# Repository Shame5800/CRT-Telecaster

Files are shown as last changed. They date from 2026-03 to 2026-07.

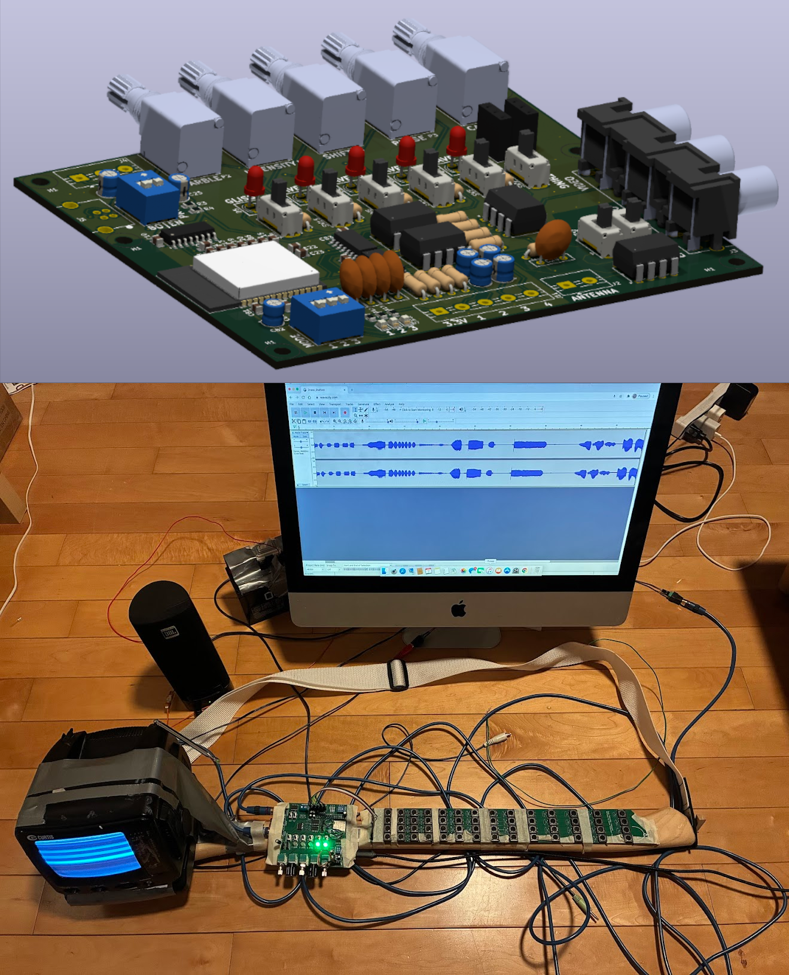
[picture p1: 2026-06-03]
hero.png

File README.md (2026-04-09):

Members

Shane Pomajambo, Electrical Engineering Student (2026)
Shanepomajambo16@vt.edu

Mentor

Arthur Ball

Current Status

IN PROGRESS

Project Overview

The purpose of this project is to create the CRT Telecaster guitars used by the Band ELECTRONICOS FANTASTICOS (https://www.youtube.com/@ELECTRONICOSFANTASTICOS_YT). The way it works is that audio signals such as square, sine, and triangle waves are sent to the video jack of a CRT television, which leads it to display the wave in the form of white and black bars. Since CRTs are a significant source of EM radiation, the EM waves can be picked up with either an inductor or by connecting the + end of an active speaker system and inducing voltage through the capacitive effect of touching the screen. Notes can be played, and the sound can be changed by moving your hand closer or farther to the screen, similar to a therevin type insturment.

The design of this instrument uses a Driver PCB equipped with an ESP32. The DAC modules built into the dev board act as a wave generator, which generates sound waves to feed into the CRT input. In order to play a certain note, 4 ADC pins with 1K resistors to ground are connected to a button and resistor array that form a 3.3V voltage divider. Values are chosen in order to be 0.15V, and each button represented a fret, similar to how a guitar would be played. Several buttons and knobs are also included to have programable affects, such as changing the type of wave, holding inputs, or having sound effects.

Through other Virginia Tech maker spaces, a working prototype has been created. However, issues still exist with grounding, playing different notes, reliability, and compactness. The main goal of the project will be to further improve the design.

Educational Value Added

One primary educational aspect of the project will be the development of the PCB. Through other personal projects using copper plate PCBS and working on debugging boards on design teams, I have become very familiar with KiCAD. This project will allow me to continue developing this skill while also introducing me to the proper PCB design principles and standards in the industry. The first educational aspect of the redesign of the telecasters' driver board is that I’m aiming to include an onboard ESP32 WROOM chip rather than a dev board, as it would give me exposure to integrating microprocessors directly on the board with programmer chips and USB ports for a more finished product. In addition, since previous designs had relied on copper plate milling and therefore had to follow different design considerations, I can focus on making the redesign compact, easy to interface with , and following proper PCB design principles.

There is also lots of educational value in programming as well. The inclusion of SPI DAC modules or other devices will expose me to embedded systems. In addition, I’ll be able to practice using hardware interrupts and optimizing code when controlling the wave generator.

The project’s development as a whole will give me lots of experience in planning, cost management/optimization, and debugging. Additionally, since very little information exists on how ELECTRONICOS FANTASTICOS’s instruments work, I'm also planning on creating tutorials and documentation on the project’s progress, giving me experience with open source documentation and technical writing.

Tasks

<!-- Your Text Here. You may work with your mentor on this later when they are assigned -->

Design Decisions

<!-- Your Text Here. You may work with your mentor on this later when they are assigned -->

Design Misc

<!-- Your Text Here. You may work with your mentor on this later when they are assigned -->

Steps for Documenting Your Design Process

<!-- Your Text Here. You may work with your mentor on this later when they are assigned -->

BOM + Component Cost

<!-- Your Text Here. You may work with your mentor on this later when they are assigned -->

Timeline

<!-- Your Text Here. You may work with your mentor on this later when they are assigned -->

Useful Links

<!-- Your Text Here. You may work with your mentor on this later when they are assigned -->

Log

<!-- Your Text Here. You may work with your mentor on this later when they are assigned -->

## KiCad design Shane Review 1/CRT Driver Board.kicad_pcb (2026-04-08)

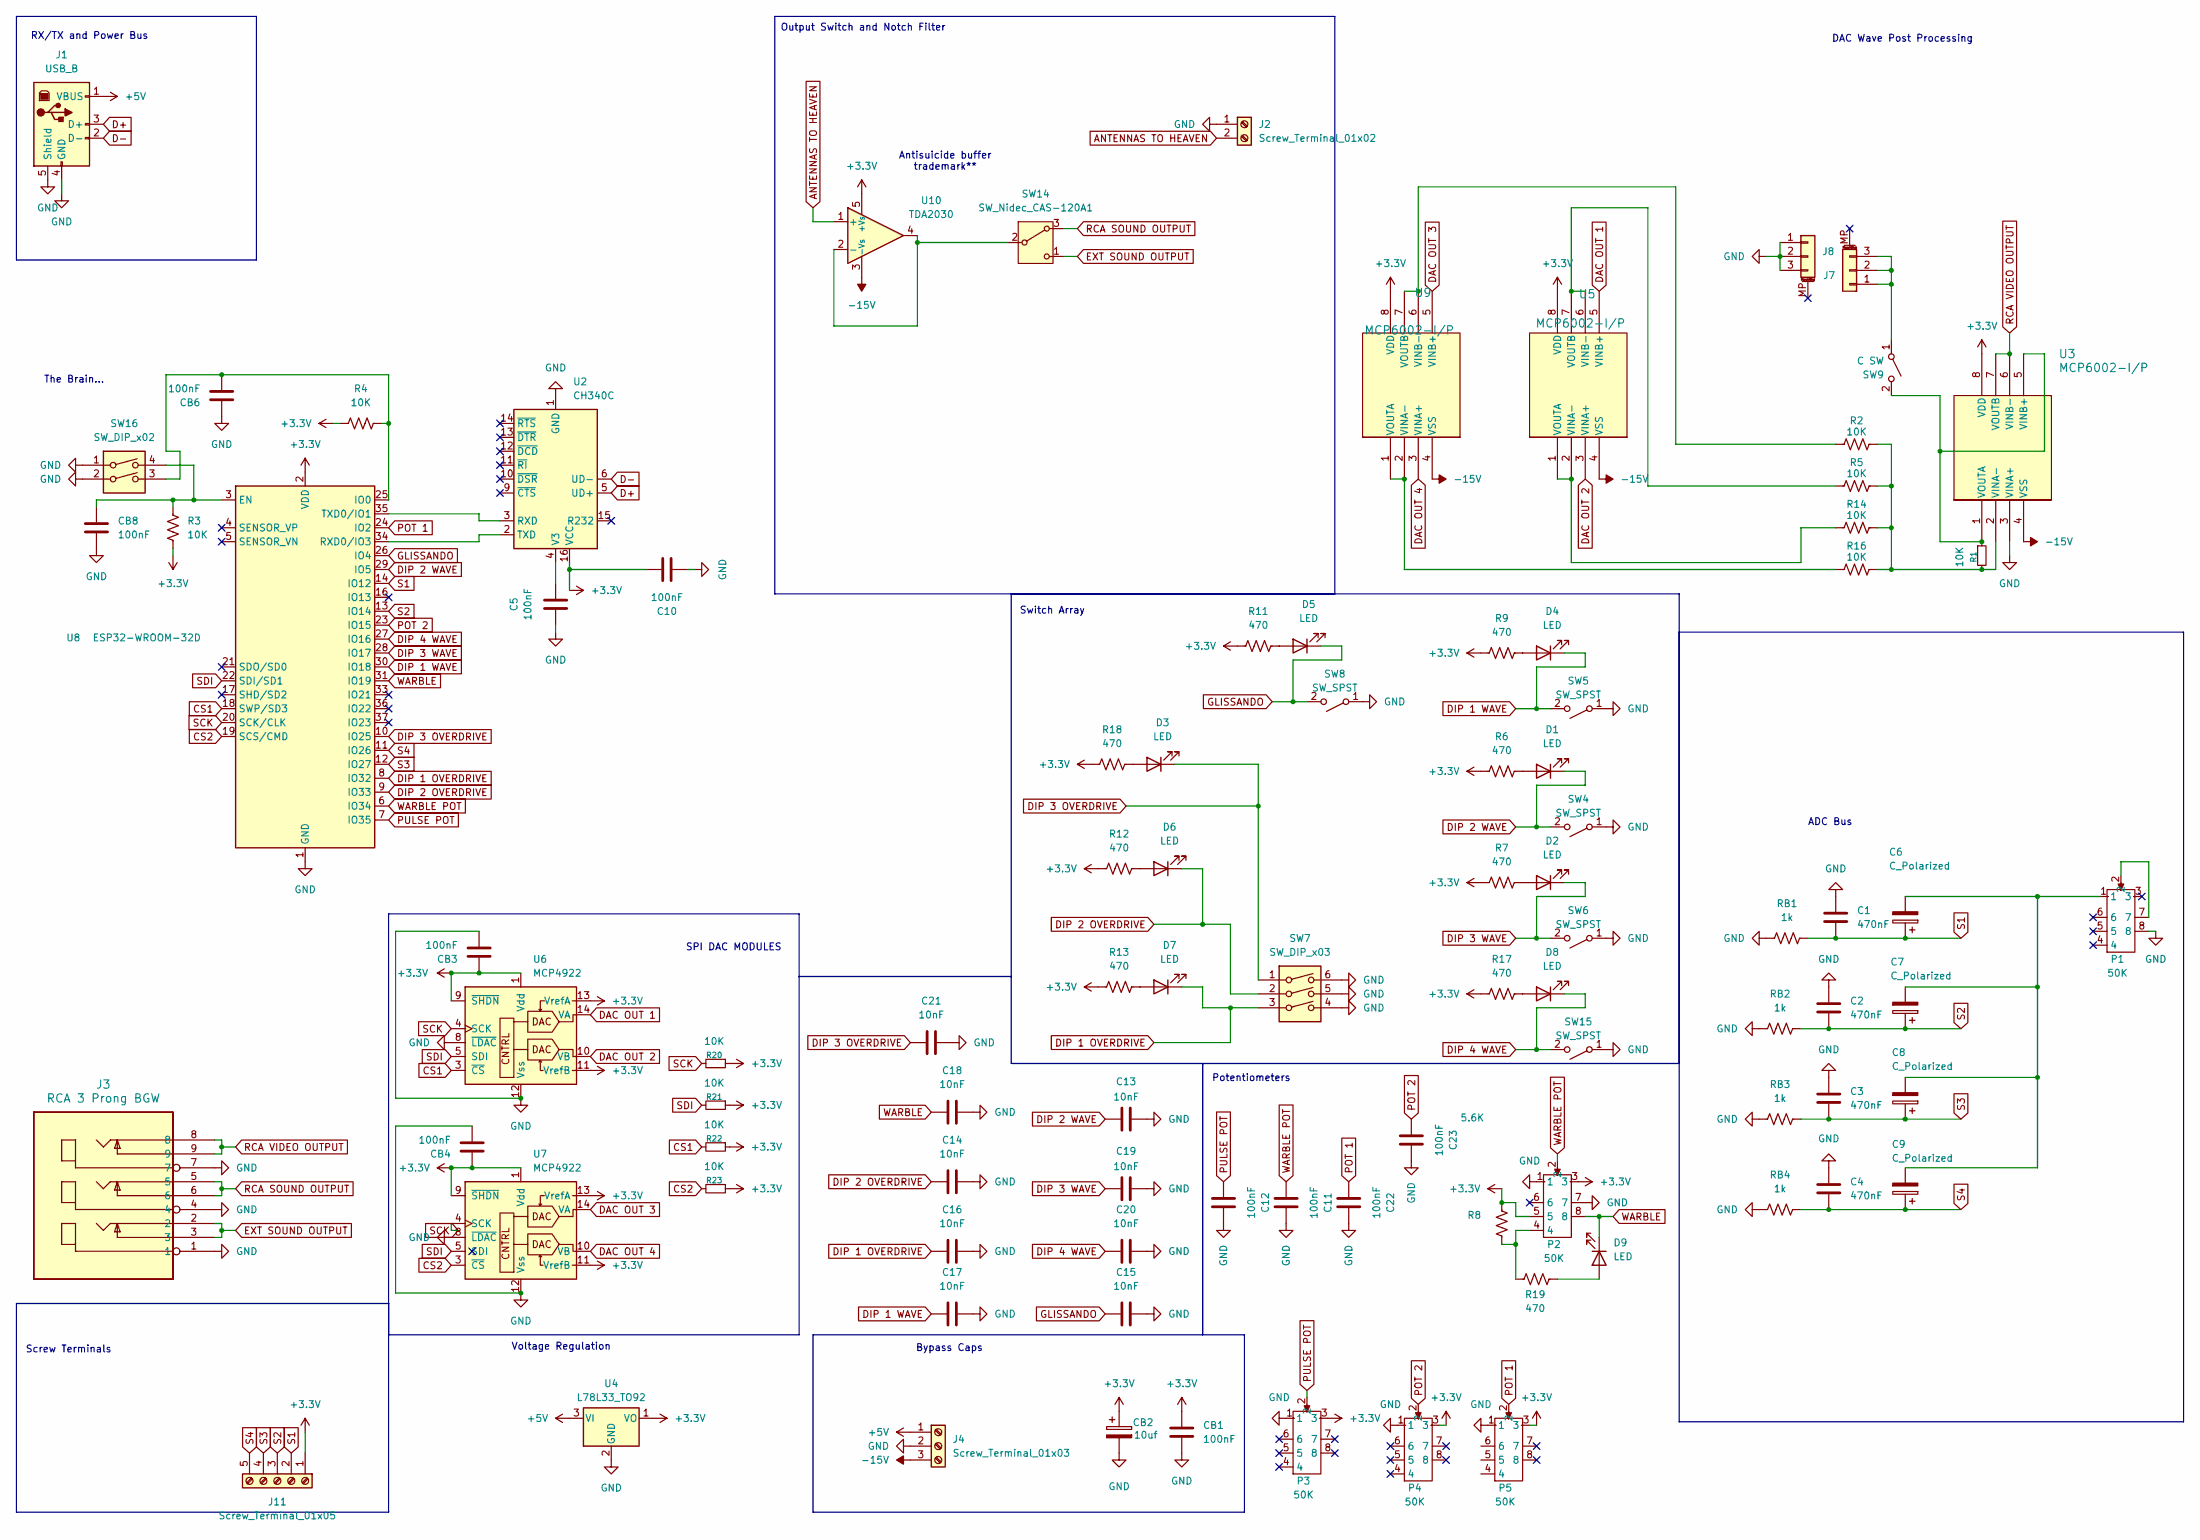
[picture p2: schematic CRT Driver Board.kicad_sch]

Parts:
C1, C2, C3, C4: 470nF; C_Disc_D8.0mm_W2.5mm_P5.00mm
C5, C10, C11, C12: 100nF; C_0805_2012Metric
C6, C7, C8, C9: C_Polarized; CP_Radial_D4.0mm_P2.00mm
C13, C14, C15, C16, C17, C18, C19, C20, C21: 10nF; C_0805_2012Metric
C22, C23: 100nF; C_0805_2012Metric_Pad1.18x1.45mm_HandSolder
CB1, CB3, CB4, CB6, CB8: 100nF; C_0805_2012Metric
CB2: 10uf; CP_Radial_D4.0mm_P2.00mm
D1, D2, D4, D5, D8, D9: LED; LED_D3.0mm
D3, D6, D7: LED; LED_0805_2012Metric
J1: USB_B; USB_B_TE_5787834_Vertical
J2: Screw_Terminal_01x02; TerminalBlock_MaiXu_MX126-5.0-02P_1x02_P5.00mm
J3: RCA 3 Prong BGW; RCA 3 Prong
J4: Screw_Terminal_01x03; TerminalBlock_MaiXu_MX126-5.0-03P_1x03_P5.00mm
J7, J8: Conn_01x03_MountingPin; PinSocket_1x03_P2.54mm_Vertical
J11: Screw_Terminal_01x05; TerminalBlock_MaiXu_MX126-5.0-05P_1x05_P5.00mm
P1, P2, P3, P4, P5: 50K; Potentiometer_Alps_RK097_Dual_Horizontal_Switch
R1, R2, R5, R14, R16: 10K; R_Axial_DIN0207_L6.3mm_D2.5mm_P7.62mm_Horizontal
R3, R4: 10K; R_0805_2012Metric
R6, R7, R9, R11, R17, R19: 470; R_Axial_DIN0207_L6.3mm_D2.5mm_P7.62mm_Horizontal
R8: 5.6K; R_Axial_DIN0207_L6.3mm_D2.5mm_P7.62mm_Horizontal
R12, R13, R18: 470; R_0805_2012Metric
R20, R21, R22, R23: 10K; R_0805_2012Metric_Pad1.20x1.40mm_HandSolder
RB1, RB2, RB3, RB4: 1k; R_Axial_DIN0207_L6.3mm_D2.5mm_P7.62mm_Horizontal
SW4, SW5, SW6, SW8, SW15: SW_SPST; SW_Slide_SPDT_Straight_CK_OS102011MS2Q
SW7: SW_DIP_x03; SW_DIP_SPSTx03_Slide_9.78x9.8mm_W7.62mm_P2.54mm
SW9: C SW; SW_Slide_SPDT_Straight_CK_OS102011MS2Q
SW14: SW_Nidec_CAS-120A1; 3 way switch
SW16: SW_DIP_x02; SW_DIP_SPSTx02_Slide_9.78x7.26mm_W7.62mm_P2.54mm
U2: CH340C; SOIC-16_3.9x9.9mm_P1.27mm
U3, U5, U9: MCP6002-I/P; PDIP8_300MC_MCH
U4: L78L33_TO92; TO-92L
U6, U7: MCP4922
U8: ESP32-WROOM-32D; esp32 WROOM without that FUCKASS attenna
U10: TDA2030; TO-220-5_P3.4x3.8mm_StaggerOdd_Lead7.13mm_TabDown

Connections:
+3.3V: C10.1, CB1.2, CB2.1, CB3.2, CB4.2, J11.1, P2.3, P2.5, P3.3, P4.3, P5.3, R3.2, R4.1, R6.1, R7.1, R8.2, R9.1, R11.1, R12.1, R13.1, R17.1, R18.1, R20.1, R21.1, R22.1, R23.1, U2.16 (VCC), U3.8 (VDD), U4.1 (VO), U5.8 (VDD), U6.1 (Vdd), U6.9 (~SHDN), U6.11 (VrefB), U6.13 (VrefA), U7.1 (Vdd), U7.9 (~SHDN), U7.11 (VrefB), U7.13 (VrefA), U8.2 (VDD), U9.8 (VDD), U10.5 (+Vs)
+5V: J1.1 (VBUS), J4.1, U4.3 (VI)
-15V: J4.3, U3.4 (VSS), U5.4 (VSS), U9.4 (VSS), U10.3 (-Vs)
ANTENNAS TO HEAVEN: J2.2, U10.1 (+)
CS1: R22.2, U6.3 (~CS), U8.18 (SWP/SD3)
CS2: R23.2, U7.3 (~CS), U8.19 (SCS/CMD)
D+: J1.3 (D+), U2.5 (UD+)
D-: J1.2 (D-), U2.6 (UD-)
DAC OUT 1: U5.5 (VINB+), U6.14 (VA)
DAC OUT 2: U5.3 (VINA+), U6.10 (VB)
DAC OUT 3: U7.14 (VA), U9.5 (VINB+)
DAC OUT 4: U7.10 (VB), U9.3 (VINA+)
DIP 1 OVERDRIVE: C16.2, D7.1 (K), SW7.3, U8.8 (IO32)
DIP 1 WAVE: C17.2, D4.1 (K), SW5.2 (B), U8.30 (IO18)
DIP 2 OVERDRIVE: C14.2, D6.1 (K), SW7.2, U8.9 (IO33)
DIP 2 WAVE: C13.2, D1.1 (K), SW4.2 (B), U8.29 (IO5)
DIP 3 OVERDRIVE: C21.2, D3.1 (K), SW7.1, U8.10 (IO25)
DIP 3 WAVE: C19.2, D2.1 (K), SW6.2 (B), U8.28 (IO17)
DIP 4 WAVE: C20.2, D8.1 (K), SW15.2 (B), U8.27 (IO16)
EXT SOUND OUTPUT: J3.2, J3.3, SW14.1 (C)
GLISSANDO: C15.2, D5.1 (K), SW8.2 (B), U8.26 (IO4)
GND: C1.1, C2.1, C3.1, C4.1, C5.2, C10.2, C11.1, C12.1, C13.1, C14.1, C15.1, C16.1, C17.1, C18.1, C19.1, C20.1, C21.1, C22.1, C23.1, CB1.1, CB2.2, CB3.1, CB4.1, CB6.2, CB8.1, J1.4 (GND), J1.5 (Shield), J2.1, J3.1, J3.4, J3.7, J4.2, J8.1, J8.2, J8.3, P1.8, P2.1, P2.7, P3.1, P4.1, P5.1, RB1.1, RB2.1, RB3.1, RB4.1, SW4.1 (A), SW5.1 (A), SW6.1 (A), SW7.4, SW7.5, SW7.6, SW8.1 (A), SW15.1 (A), SW16.1, SW16.2, U2.1 (GND), U3.3 (VINA+), U4.2 (GND), U6.8 (~LDAC), U6.12 (Vss), U7.8 (~LDAC), U7.12 (Vss), U8.1 (GND), U8.15 (GND), U8.38 (GND), U8.39 (GND)
unnamed: C6.2, C7.2, C8.2, C9.2, P1.1
unnamed: D1.2 (A), R6.2
unnamed: D2.2 (A), R7.2
unnamed: D3.2 (A), R18.2
unnamed: D4.2 (A), R9.2
unnamed: D5.2 (A), R11.2
unnamed: D6.2 (A), R12.2
unnamed: D7.2 (A), R13.2
unnamed: D8.2 (A), R17.2
unnamed: D9.2 (A), R19.2
unnamed: J7.1, J7.2, J7.3, SW9.1 (A)
unnamed: P1.2, P1.7
unnamed: P2.4, R8.1, R19.1
unnamed: R1.1, SW9.2 (B), U3.1 (VOUTA), U3.5 (VINB+)
unnamed: SW14.2 (B), U10.2 (-), U10.4
unnamed: U2.3 (RXD), U8.35 (TXD0/IO1)
unnamed: U2.2 (TXD), U8.34 (RXD0/IO3)
unnamed: C5.1, U2.4 (V3)
unnamed: R1.2, R2.2, R5.2, R14.2, R16.2, U3.2 (VINA-)
unnamed: R14.1, U5.1 (VOUTA), U5.2 (VINA-)
unnamed: R5.1, U5.6 (VINB-), U5.7 (VOUTB)
unnamed: CB8.2, R3.1, SW16.4, U8.3 (EN)
unnamed: CB6.1, R4.2, SW16.3, U8.25 (IO0)
unnamed: R16.1, U9.1 (VOUTA), U9.2 (VINA-)
unnamed: R2.1, U9.6 (VINB-), U9.7 (VOUTB)
POT 1: C22.2, P5.2, U8.24 (IO2)
POT 2: C23.2, P4.2, U8.23 (IO15)
PULSE POT: C12.2, P3.2, U8.7 (IO35)
RCA SOUND OUTPUT: J3.5, J3.6, SW14.3 (A)
RCA VIDEO OUTPUT: J3.8, J3.9, U3.6 (VINB-), U3.7 (VOUTB)
S1: C1.2, C6.1, J11.2, RB1.2, U8.14 (IO12)
S2: C2.2, C7.1, J11.3, RB2.2, U8.13 (IO14)
S3: C3.2, C8.1, J11.4, RB3.2, U8.12 (IO27)
S4: C4.2, C9.1, J11.5, RB4.2, U8.11 (IO26)
SCK: R20.2, U6.4 (SCK), U7.4 (SCK), U8.20 (SCK/CLK)
SDI: R21.2, U6.5 (SDI), U7.5 (SDI), U8.22 (SDI/SD1)
WARBLE: C18.2, D9.1 (K), P2.8, U8.31 (IO19)
WARBLE POT: C11.2, P2.2, U8.6 (IO34)

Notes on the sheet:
ADC Bus
Potentiometers
Output Switch and Notch Filter
Switch Array
Antisuicide buffer trademark**
SPI DAC MODULES
DAC Wave Post Processing
Screw Terminals
Voltage Regulation
Bypass Caps
The Brain...
RX/TX and Power Bus

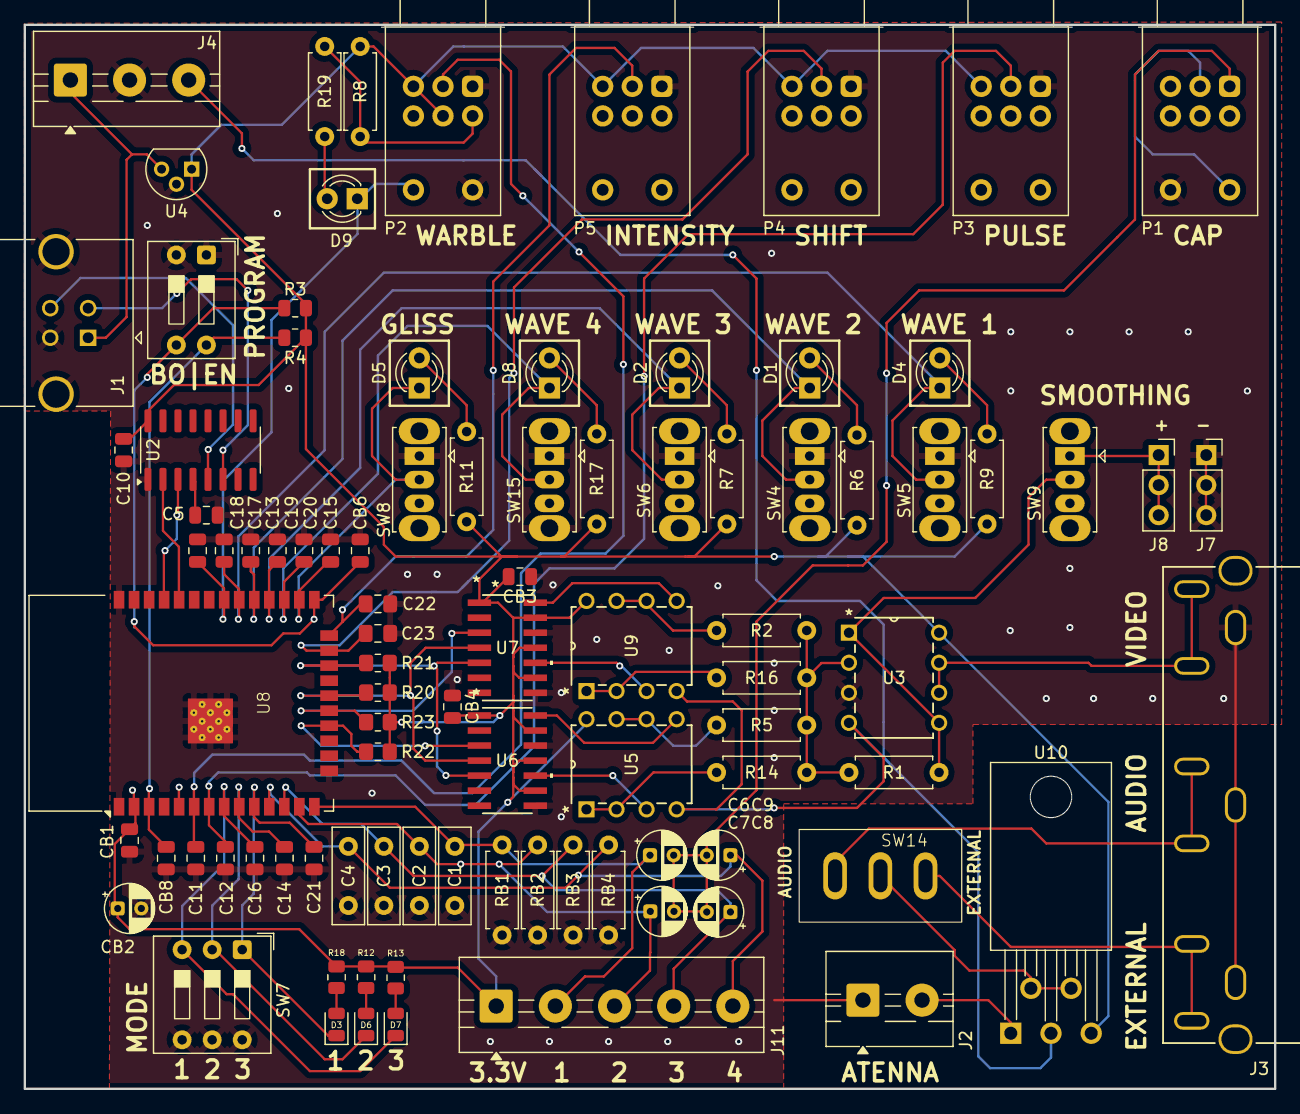
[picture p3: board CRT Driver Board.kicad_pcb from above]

Board: 2 copper layers, 105.7 x 89.9 mm, 93 parts (0 on the bottom side), 60 nets.

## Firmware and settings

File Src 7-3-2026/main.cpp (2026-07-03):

#include <Arduino.h>
#include "def.h"
#include "esp_wifi.h"
#include "esp_bt.h"
#include "global.h"
#include "wavegen.h"
#include "notes.h"
//================================================================================
//     ______           __                   _
//    /_  __/______  __/ /____  ______ ___  (_)___  __  __
//     / / / ___/ / / / //_/ / / / __ `__ \/ /_  / / / / /
//    / / (__  ) /_/ / ,< / /_/ / / / / / / / / /_/ /_/ /
//   /_/ /____/\__,_/_/|_|\__,_/_/ /_/ /_/_/ /___/\__,_/
//
//                          ______     __                     __
//                         /_  __/__  / /__  _________ ______/ /____  _____
//                          / / / _ \/ / _ \/ ___/ __ `/ ___/ __/ _ \/ ___/
//                         / / /  __/ /  __/ /__/ /_/ /__  / /_/  __/ /
//                        /_/  \___/_/\___/\___/\__,_/____/\__/\___/_/
//
//================================================================================
// 
//Tsukumizu Progamable 4 string hybrid bass guitar
//
//    Designed by Shane Sebastian Pomajambo
//
//    Originial idea by ELECTRONICOS FANTASTICOS
//
//    Special Thanks to Elias Charron, Shane Wyman, Professor Arthur Ball, and the AMP Lab at Virginia Tech
//
// Ver 2.1
// - We're in VSCode Now!
// - Created V2 PCB
// - This code is designed for the V2 PCB, and is much diffrent
// - 4 channel DACs based on SPI
// - More potential wave options plus mode selector
// - combined interupts logic with dual core architecture of ESP32
//
//
//
//
//
// Tuning =========================================================================

//Standard
int manualModifiers[] = {0,0,0,0};

//Tune down 2 frets, Used in Yoshi's Island by Glass Beach
//int manualModifiers[] = {-2,-2,-2,-2};



// Synchronous Methods ============================================================
//
//Set true for chorus, set false for octaver
bool chorus = false;
//
//
//Note Array
int notes[] = {
  Bb0,B0note,C1,Db1,D1,Eb1, E1, F1, Gb1, G1, Ab1, A1, Bb1, B1note,
  C2, Db2, D2, Eb2, E2, F2, Gb2, G2, Ab2, A2, Bb2, B2,
  C3, Db3, D3, Eb3, E3, F3, Gb3, G3, Ab3, A3, Bb3, B3,
  C4, Db4, D4, Eb4, E4, F4, Gb4, G4, Ab4, A4, Bb4, B4,
  C5, Db5, D5, Eb5, E5, F5, Gb5, G5, Ab5, A5, Bb5, B5,
  C6, Db6, D6, Eb6, E6, F6
};

//sendToWavegen() Variables
uint32_t tempPhaseIncrementChannelOne=0;
uint32_t tempPhaseIncrementChannelTwo=0;
uint32_t tempPhaseIncrementChannelThree=0;
uint32_t tempPhaseIncrementChannelFour=0;
int tempMultiplierChannelOne=0;
int tempMultiplierChannelTwo=0;
int tempMultiplierChannelThree=0;
int tempMultiplierChannelFour=0;
int tempWaveSelector=0;
hw_timer_t *timer = NULL;

//Potentiometer and user input
bool warble = false;
bool glissando = false;
int warblePot = 0;
int intensityPot=0;
int shiftPot=0;
int tempPulsePot = 0;
int modeSelector=0;

//Warble mode
int warbleDivisor;
int warbleCounter=0;
bool upwardsWarble=false;

//Shift Mode
int shiftRange=0;
int shiftModifier=0;

//Fretboard input processing
int lastPlayedFret[] = {-1,-1,-1,-1};
int requestedNote[] = {0,0,0,0};
int requestedFret[] = {-1,-1,-1,-1};
int numNotesPlaying = 0;
int totalMultiplier=0;
int noteBases[] = {6,6,6,6};

//Methods ---------------------------------------------------------------
void setFrequencies(float freq1,float freq2,float freq3,float freq4) { //Converts frequencies to increment
  // phaseIncrement = (freq * 2^32) / SAMPLE_RATE
  tempPhaseIncrementChannelOne = (uint32_t)((freq1 * 4294967296.0) / 20000);
  tempPhaseIncrementChannelTwo = (uint32_t)((freq2 * 4294967296.0) / 20000);
  tempPhaseIncrementChannelThree = (uint32_t)((freq3 * 4294967296.0) / 20000);
  tempPhaseIncrementChannelFour = (uint32_t)((freq4 * 4294967296.0) / 20000);
}

void setMultiplier(int input1,int input2,int input3,int input4){ //Sets Multipliers
  tempMultiplierChannelOne=input1;
  tempMultiplierChannelTwo=input2;
  tempMultiplierChannelThree=input3;
  tempMultiplierChannelFour=input4;
}

void sendToWaveGenerator(){ //Helper method used by sendNotes()
  portENTER_CRITICAL(&mux);
  phaseIncrementChannelOne = tempPhaseIncrementChannelOne;
  phaseIncrementChannelTwo = tempPhaseIncrementChannelTwo;
  phaseIncrementChannelThree = tempPhaseIncrementChannelThree;
  phaseIncrementChannelFour = tempPhaseIncrementChannelFour;
  multiplierChannelOne = tempMultiplierChannelOne;
  multiplierChannelTwo = tempMultiplierChannelTwo;
  multiplierChannelThree = tempMultiplierChannelThree;
  multiplierChannelFour = tempMultiplierChannelFour;
  waveSelector = tempWaveSelector;
  pulsePot = tempPulsePot;
  portEXIT_CRITICAL(&mux);
}

int processInput(int input) { //Process ADC to Fret
  input = input - 1020;
  int multiple = input / 200;
  if (input - multiple * 200 > 100) {
    multiple = multiple + 1;
  }
  if(multiple<0){
    return -1;
  }
  numNotesPlaying++;
  return multiple;
}  //end process

void playTuningChorale(){ 
  
  //In Honor of Mr Martin.
    

  setMultiplier(0,0,0,0);
  sendToWaveGenerator();
  delay(5000);
  setMultiplier(16,16,16,0);
  setFrequencies(A2,A3,A4,B5); sendToWaveGenerator(); delay(1000);
  setMultiplier(0,0,0,0); sendToWaveGenerator(); delay(50); setMultiplier(16,16,16,0);
  setFrequencies(G2,G3,G4,B5); sendToWaveGenerator(); delay(1000);
  setMultiplier(0,0,0,0); sendToWaveGenerator(); delay(50); setMultiplier(16,16,16,0);
  setFrequencies(G2,G3,G4,B5); sendToWaveGenerator(); delay(1000);
  setMultiplier(0,0,0,0); sendToWaveGenerator(); delay(50); setMultiplier(16,16,16,0);
  setFrequencies(F2,F3,F4,B5); sendToWaveGenerator(); delay(1000);
  setMultiplier(0,0,0,0); sendToWaveGenerator(); delay(50); setMultiplier(16,16,16,0);
  setFrequencies(F2,F3,F4,B5); sendToWaveGenerator(); delay(1000);
  setMultiplier(0,0,0,0); sendToWaveGenerator(); delay(50); setMultiplier(16,16,16,0);
  setFrequencies(F2,F3,F4,B5); sendToWaveGenerator(); delay(1000);
  setMultiplier(0,0,0,0); sendToWaveGenerator(); delay(50); setMultiplier(16,16,16,0);
  setFrequencies(E2,E3,E4,B5); sendToWaveGenerator(); delay(1000);
  setMultiplier(0,0,0,0); sendToWaveGenerator(); delay(50); setMultiplier(16,16,16,0);
  setFrequencies(F2,F3,F4,B5); sendToWaveGenerator(); delay(2000);
  setMultiplier(0,0,0,0);  sendToWaveGenerator(); delay(1000); setMultiplier(16,16,16,0);
  setFrequencies(F2,F3,F4,B5); sendToWaveGenerator(); delay(1000);
  setMultiplier(0,0,0,0); sendToWaveGenerator(); delay(50); setMultiplier(16,16,16,0);
  setFrequencies(G2,G3,G4,B5); sendToWaveGenerator(); delay(1000);
  setMultiplier(0,0,0,0); sendToWaveGenerator(); delay(50); setMultiplier(16,16,16,0);
  setFrequencies(G2,G3,G4,B5); sendToWaveGenerator(); delay(1000);
  setMultiplier(0,0,0,0); sendToWaveGenerator(); delay(50); setMultiplier(16,16,16,0);
  setFrequencies(A2,A3,A4,B5); sendToWaveGenerator(); delay(1000);
  setMultiplier(0,0,0,0); sendToWaveGenerator(); delay(50); setMultiplier(16,16,16,0);
  setFrequencies(F2,F3,F4,B5); sendToWaveGenerator(); delay(1000);
  setMultiplier(0,0,0,0); sendToWaveGenerator(); delay(50); setMultiplier(16,16,16,0);
  setFrequencies(Bb2,Bb3,Bb4,B5); sendToWaveGenerator(); delay(1000);
  setMultiplier(0,0,0,0); sendToWaveGenerator(); delay(50); setMultiplier(16,16,16,0);
  setFrequencies(Bb2,Bb3,Bb4,B5); sendToWaveGenerator(); delay(1000);
  setMultiplier(0,0,0,0); sendToWaveGenerator(); delay(50); setMultiplier(16,16,16,0);
  setFrequencies(A2,A3,A4,B5); sendToWaveGenerator(); delay(2000);
  setMultiplier(0,0,0,0); sendToWaveGenerator(); delay(50); setMultiplier(16,16,16,0);
  setFrequencies(F2,F3,F4,B5); sendToWaveGenerator(); delay(4000);
  setMultiplier(0,0,0,0); sendToWaveGenerator();
}

void sendNotes(){ //Send note selections to processing
  if(requestedNote[0]!=0){tempMultiplierChannelOne=totalMultiplier;} else{tempMultiplierChannelOne=0;}
  if(requestedNote[1]!=0){tempMultiplierChannelTwo=totalMultiplier;} else{tempMultiplierChannelTwo=0;}
  if(requestedNote[2]!=0){tempMultiplierChannelThree=totalMultiplier;} else{tempMultiplierChannelThree=0;}
  if(requestedNote[3]!=0){tempMultiplierChannelFour=totalMultiplier;} else{tempMultiplierChannelFour=0;}
  setFrequencies(requestedNote[0],requestedNote[1],requestedNote[2],requestedNote[3]);
  sendToWaveGenerator();
  lastPlayedFret[0]=requestedFret[0];
  lastPlayedFret[1]=requestedFret[1];
  lastPlayedFret[2]=requestedFret[2];
  lastPlayedFret[3]=requestedFret[3];
}

void processSwitches(){ //Process Mode and Wave DIP switches
  
  //Take UI measurements
  if(digitalRead(GLISSANDOPIN)==LOW){glissando=true;}
  else{glissando=false;}
  if(digitalRead(WARBLEPIN)==LOW){warble=true;}
  else{warble=false;}

  modeSelector=0;
  if(digitalRead(MODEDIP1PIN)==LOW){modeSelector+=1;}
  if(digitalRead(MODEDIP2PIN)==LOW){modeSelector+=2;}
  if(digitalRead(MODEDIP3PIN)==LOW){modeSelector+=4;}

  tempWaveSelector=0;
  if(digitalRead(WAVEDIP1PIN)==LOW){tempWaveSelector+=1;}
  if(digitalRead(WAVEDIP2PIN)==LOW){tempWaveSelector+=2;}
  if(digitalRead(WAVEDIP3PIN)==LOW){tempWaveSelector+=4;}
  if(digitalRead(WAVEDIP4PIN)==LOW){tempWaveSelector+=8;}
  
  //Base Mode Logic
  //4 string bass
  noteBases[0]=6;
  noteBases[1]=6;
  noteBases[2]=6;
  noteBases[3]=6;
  if(modeSelector==1){ //guitar lower
    noteBases[0]=18;
    noteBases[1]=18;
    noteBases[2]=18;
    noteBases[3]=18;
  }
  if(modeSelector==2){ //guitar middle
    noteBases[0]=23;
    noteBases[1]=23;
    noteBases[2]=23;
    noteBases[3]=22;
  }
  if(modeSelector==3){ //guitar higher
    noteBases[0]=28;
    noteBases[1]=28;
    noteBases[2]=27;
    noteBases[3]=27;
  }
  if(modeSelector==4){ //5 string bass lower, upper is 4 string bass
    noteBases[0]=1;
    noteBases[1]=1;
    noteBases[2]=1;
    noteBases[3]=1;
  }
  if(modeSelector==5){ //Overdrive Guitar
   noteBases[0]=38;
    noteBases[1]=38;
    noteBases[2]=37;
    noteBases[3]=37;

  }
  if(modeSelector==6){ //overdrive bass
    noteBases[0]=16;
    noteBases[1]=16;
    noteBases[2]=16;
    noteBases[3]=16;
  }
  if(modeSelector==7){
    //TBD 
    //preset modes for autoplay eventually
  }
}

void processOctaver(){ //Process Octaver or Chorus modes
  if(tempWaveSelector>=8){
    for(int i=0;i<4;i++){
      if(requestedNote[i]!=0){
        int currentNoteIndex = requestedFret[i] + (i*5) + manualModifiers[i] + noteBases[i];
        requestedNote[0]=0; requestedNote[1]=0; requestedNote[2]=0; requestedNote[3]=0;
        numNotesPlaying=0;
        if(chorus){
          requestedNote[0] = notes[currentNoteIndex];
          requestedNote[1] = notes[currentNoteIndex];
          requestedNote[2] = notes[currentNoteIndex];
          numNotesPlaying=3;
          
        }
        else{
          requestedNote[0] = notes[currentNoteIndex];
          numNotesPlaying++;
          if(currentNoteIndex-12>=0){
            requestedNote[1] = notes[currentNoteIndex-12];
            numNotesPlaying++;
          }
          if(currentNoteIndex+12<68){
            requestedNote[2] = notes[currentNoteIndex+12];
            numNotesPlaying++;
          }
        }
        break;
      }
    }
    tempWaveSelector=tempWaveSelector-8;
  }
}

void processShift(){ //Process Shift effect
  if(shiftPot>100){
    for(int i=0;i<4;i++){
      if(requestedNote[i]!=0){
        shiftRange = 2*(requestedNote[i]/30);
        
        shiftModifier = shiftPot/(4095/shiftRange);
        shiftModifier = shiftModifier - (shiftRange/2);

        requestedNote[i] = requestedNote[i]+shiftModifier;

      }
    }
  }
}


//Startup -------
void setup(){
  Serial.begin(9600);
  esp_wifi_stop();
  esp_bt_controller_disable();

  pinMode(CS1,OUTPUT);
  pinMode(CS2,OUTPUT);
 
  pinMode(S1,INPUT);
  pinMode(S2,INPUT);
  pinMode(S3,INPUT);
  pinMode(S4,INPUT);

  pinMode(WARBLEPOT,INPUT);
  pinMode(PULSEPOT,INPUT);
  pinMode(INTENSITYPOT,INPUT);
  pinMode(SHIFTPOT,INPUT);

  pinMode(GLISSANDOPIN,INPUT_PULLUP);
  pinMode(WARBLEPIN,INPUT_PULLUP);

  pinMode(WAVEDIP1PIN,INPUT_PULLUP);
  pinMode(WAVEDIP2PIN,INPUT_PULLUP);
  pinMode(WAVEDIP3PIN,INPUT_PULLUP);
  pinMode(WAVEDIP4PIN,INPUT_PULLUP);

  pinMode(MODEDIP1PIN,INPUT_PULLUP);
  pinMode(MODEDIP2PIN,INPUT_PULLUP);
  pinMode(MODEDIP3PIN,INPUT_PULLUP);

  spi.begin(SCK_PIN, -1, MOSI_PIN, -1);
  spi.beginTransaction(SPISettings(20000000, MSBFIRST, SPI_MODE0));

  digitalWrite(CS1, LOW);
  spi.transfer16(0x3000);   
  spi.transfer16(0xB000); 
  digitalWrite(CS1, HIGH);
  digitalWrite(CS2, LOW);
  spi.transfer16(0x3000);   
  spi.transfer16(0xB000); 
  digitalWrite(CS2, HIGH);

  modeSelector=0;
  if(digitalRead(MODEDIP1PIN)==LOW){modeSelector+=1;}
  if(digitalRead(MODEDIP2PIN)==LOW){modeSelector+=2;}
  if(digitalRead(MODEDIP3PIN)==LOW){modeSelector+=4;}
  Serial.println("Startup Msg");

  //May not workVVV   //It works

  xTaskCreatePinnedToCore(
    dacTask,        // function
    "DAC",          // name
    4096,           // stack size
    NULL,           // parameters
    2,              // priority
    &dacTaskHandle, // handle
    0               // core 0
  );
  


  timer = timerBegin(0, 80, true);
  timerAttachInterrupt(timer, &onTimer, true);
  timerAlarmWrite(timer, 50, true);
  timerAlarmEnable(timer);

  modeSelector=0;
  if(digitalRead(MODEDIP1PIN)==LOW){modeSelector+=1;}
  if(digitalRead(MODEDIP2PIN)==LOW){modeSelector+=2;}
  if(digitalRead(MODEDIP3PIN)==LOW){modeSelector+=4;}

  if(modeSelector==7){
    playTuningChorale();
  }


}//end setup


//Application Loop
void loop(){

  //Fret Debugging
  // int reading = analogRead(S1);
  // Serial.println(reading);
  // Serial.println(processInput(reading));
  // delay(100);

  
  delay(25);
  
  if(glissando){
    delay(75+(intensityPot));
  }

  //Process Switiches
  processSwitches();
  
  //Process Potentiometers
  tempPulsePot=analogRead(PULSEPOT);
  tempPulsePot=10+(tempPulsePot/19);

  intensityPot = analogRead(INTENSITYPOT)/41;

  shiftPot = analogRead(SHIFTPOT);

  warblePot = analogRead(WARBLEPOT);
  warbleDivisor = 60-(warblePot/136);

  //Take fret readings
  numNotesPlaying=0;
  requestedFret[0] = processInput(analogRead(S1));
  requestedFret[1] = processInput(analogRead(S2));
  requestedFret[2] = processInput(analogRead(S3));
  requestedFret[3] = processInput(analogRead(S4));

  //Process frets into notes. -1 means not pressed for fret. note of = 0 means silence 
  requestedNote[0] = 0; requestedNote[1] = 0; requestedNote[2] = 0; requestedNote[3] = 0;
  if(requestedFret[0]!=-1){requestedNote[0] = notes[noteBases[0] + manualModifiers[0] + requestedFret[0]];}
  if(requestedFret[1]!=-1){requestedNote[1] = notes[noteBases[1] + 5 + manualModifiers[1] + requestedFret[1]];}
  if(requestedFret[2]!=-1){requestedNote[2] = notes[noteBases[2] + 10 + manualModifiers[2] + requestedFret[2]];}
  if(requestedFret[3]!=-1){requestedNote[3] = notes[noteBases[3] + 15 + manualModifiers[3] + requestedFret[3]];}
  
  processOctaver();

  processShift();

  //Process warble
  if(warble==true&&glissando==false){
    if(upwardsWarble){
      warbleCounter++;
    }
    else{
      warbleCounter--;
    }
    if(warbleCounter>1){
      warbleCounter=0;
      upwardsWarble=false;
    }
    if(warbleCounter<-1){
      warbleCounter=0;
      upwardsWarble=true;
    }
    for(int i=0;i<4;i++){
      requestedNote[i]=requestedNote[i]+(warbleCounter*(requestedNote[i]/warbleDivisor));
    }
  }

  //determined needed multipliers depending on amount of notes pressed 
  if(numNotesPlaying==4){totalMultiplier=12;}
  else if(numNotesPlaying==3){totalMultiplier=16;}
  else if(numNotesPlaying==2){totalMultiplier=24;}
  else if(numNotesPlaying==1){totalMultiplier=40;}
  else{totalMultiplier=0;}


  
  if(glissando==false){
    sendNotes();
  }

  if(glissando==true){
    for(int i=0;i<4;i++){
      if(requestedFret[i]!=-1&&requestedFret[i]!=lastPlayedFret[i]){
        sendNotes(); 
        break;
      }

    }
    
  } 
  

  
  
}//end application loop

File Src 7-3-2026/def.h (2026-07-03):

//SPI
#define CS1 21
#define CS2 23
#define MOSI_PIN 22
#define SCK_PIN 13
//SWITCHES
#define GLISSANDOPIN 4
#define WARBLEPIN 19
#define WAVEDIP1PIN 18
#define WAVEDIP2PIN 5
#define WAVEDIP3PIN 17
#define WAVEDIP4PIN 16

#define MODEDIP1PIN 32
#define MODEDIP2PIN 33
#define MODEDIP3PIN 25

//POTS
#define INTENSITYPOT 2
#define SHIFTPOT 15
#define WARBLEPOT 34
#define PULSEPOT 35

//DATA LINES
#define S1 12
#define S2 14
#define S3 27
#define S4 26
